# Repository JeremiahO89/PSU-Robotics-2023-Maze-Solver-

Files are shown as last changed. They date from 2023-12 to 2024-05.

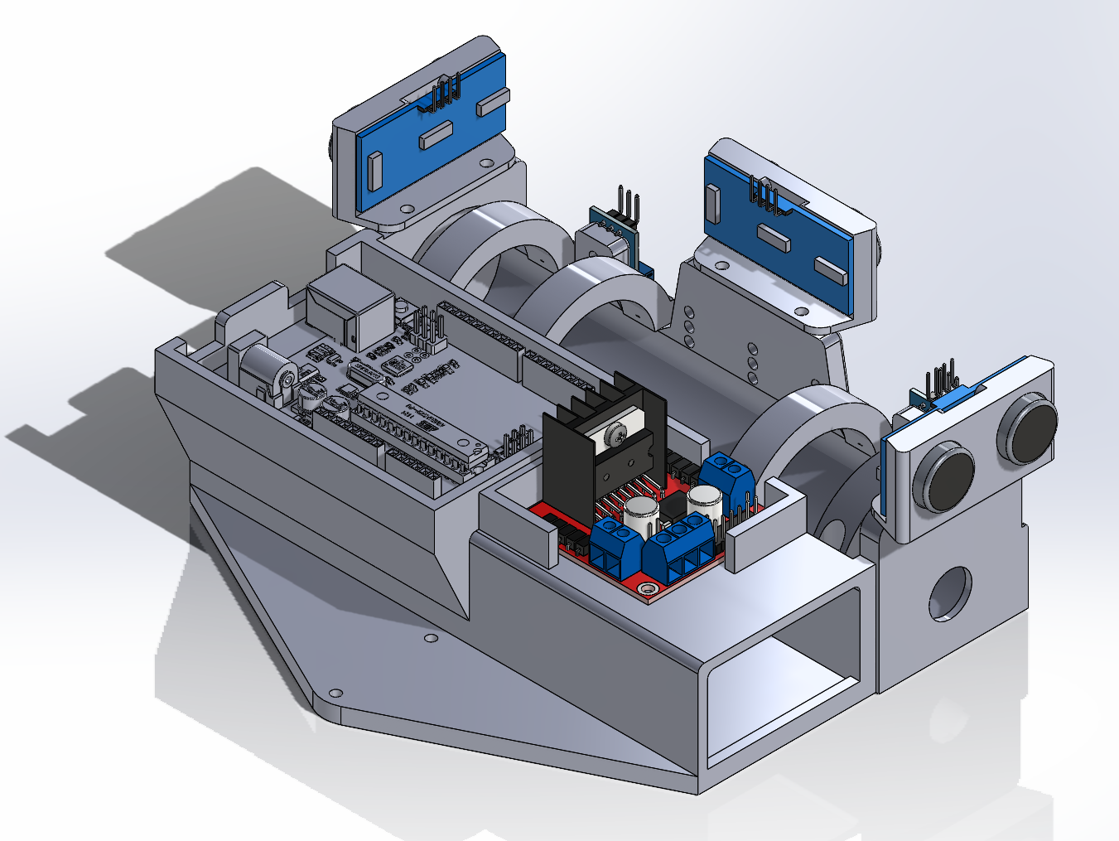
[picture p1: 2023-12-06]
Media/Screenshot 2023-12-06 145228.png

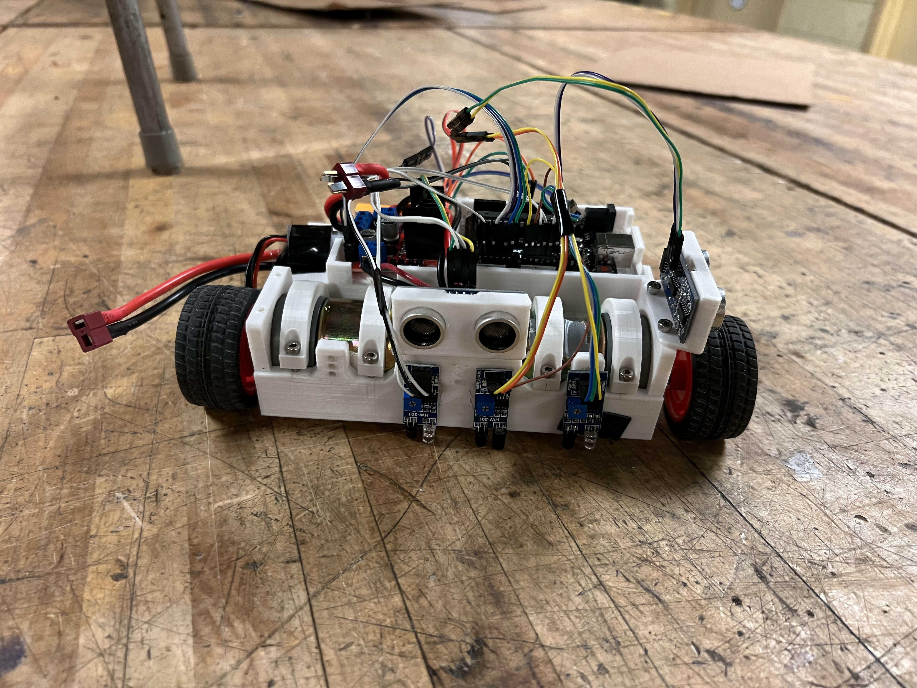
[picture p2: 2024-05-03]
Media/Finished bot.jpg

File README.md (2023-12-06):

# PSU-Robotics-2023-Maze-Solver-
This repository includes CAD and the necessary code to build a maze solving robot using basic Arduino hardware. It received 1st place at the Fall 2024 PSU Robotics Challenge 

This robot competed under the name "I Don't Care". It's design can be accredited to Jeremiah Ondrasik (jjo5541@psu.edu), Teagan Sharp (tjs6866@psu.edu), and Sydney Graver (sjg6347@psu.edu).

The CAD includes 7 SolidWorks part files and 1 assembly. To have the assembly file work correctly the files will need to properly selected when opening the file. For the final design the right Sonic sensor was not used as the Arduino didn't have enough digital pins. Also the motors, wheels and batteries weren't CADed due to time constraints. If there are any issues feel free to contact Jeremiah as he did the CAD design, Teagan helped with the robot design.

The code file nameed Challenge_Final was used on the final robot when it went to competition. The New Ping arduino library needs to be downloaded for the program to work properly. There are still a few issues with the line fowling as we ran into a major a constraint with the arduino's processing power. We originally had a very well defined line fowling code which only used the IR sensors however once we implemented the depth first searching algorithm (with the Ultrasonic sensors) we ran into processing issues of which we didn't have time to resolve (the old code is also included). This caused us to simplify the code a lot, which makes it very jerky, however it still completed the intended goal of solving the mazes within the time constant, and doing it faster than all of the other teams. If there are any questions with the code Jeremiah wrote the majority of it and Teagan / Sydney solved some of the remaining issues. 

If there are any questions about the composition Teagan should be contacted as he entered the robot into the composition.

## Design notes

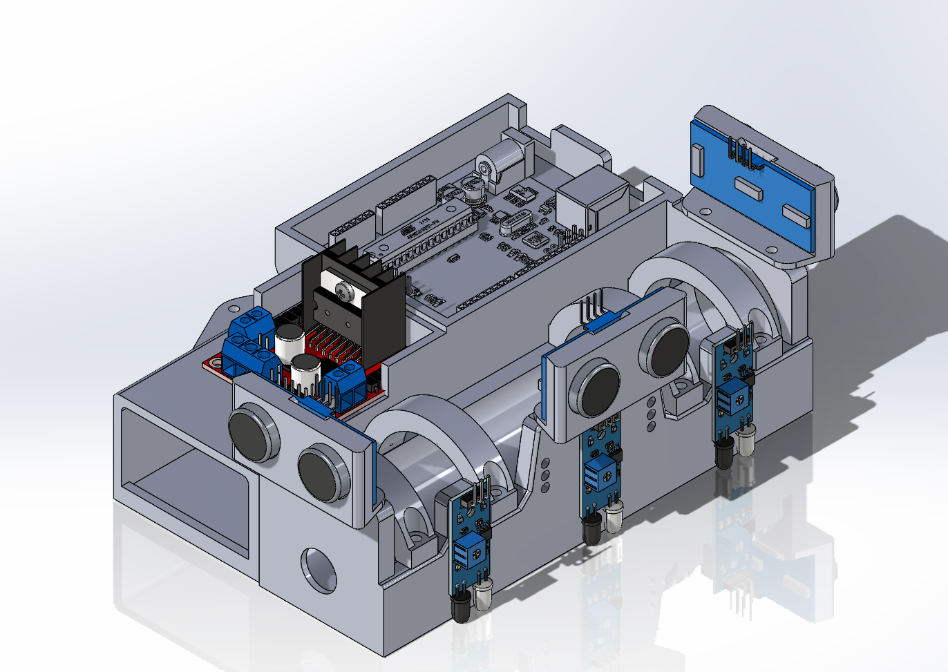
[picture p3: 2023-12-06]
Media/Screenshot 2023-12-06 145203.png

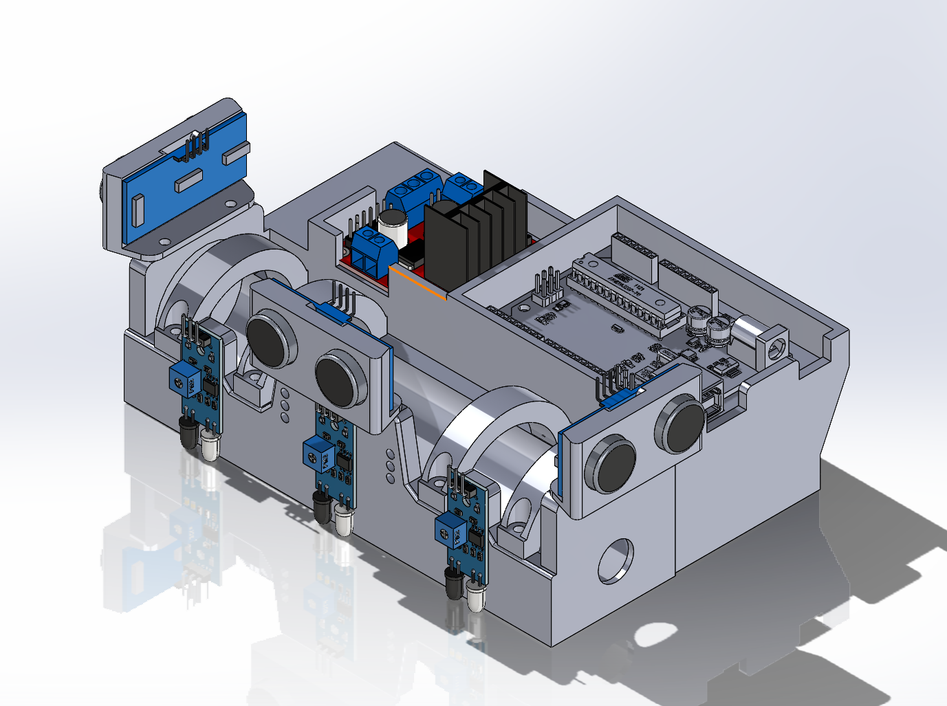
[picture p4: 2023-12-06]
Media/Screenshot 2023-12-06 145058.png

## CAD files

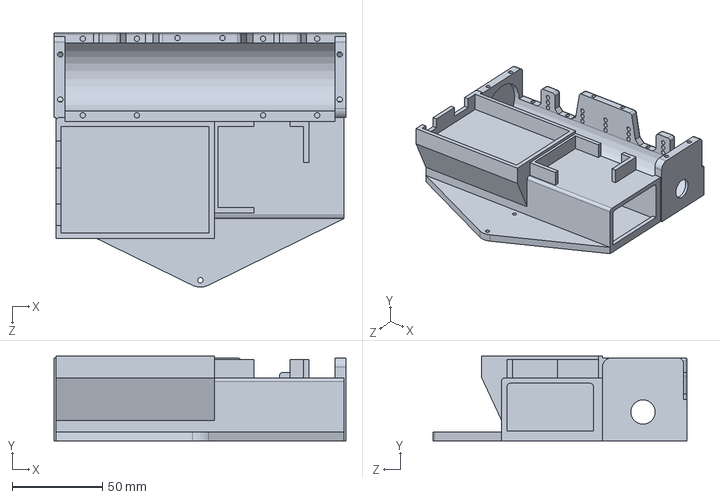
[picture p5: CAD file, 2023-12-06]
CAD/Main Chassis.SLDPRT
162.0 x 47.0 x 141.1 mm

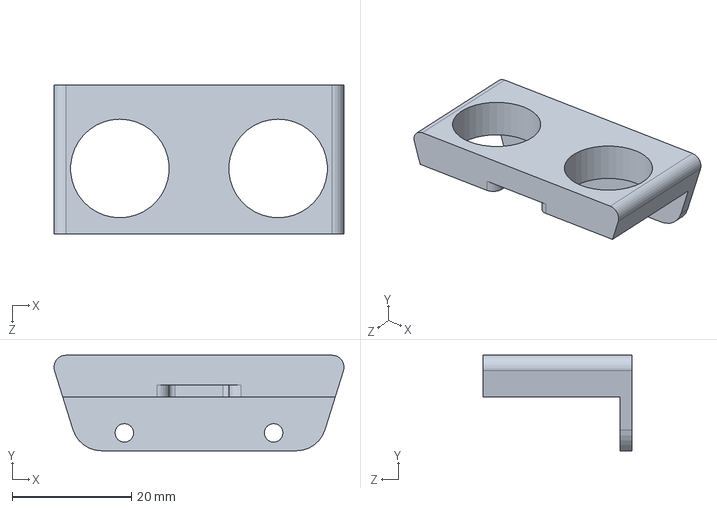
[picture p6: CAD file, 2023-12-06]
CAD/Sonic Sensor Mount.SLDPRT
48.5 x 16.0 x 25.0 mm

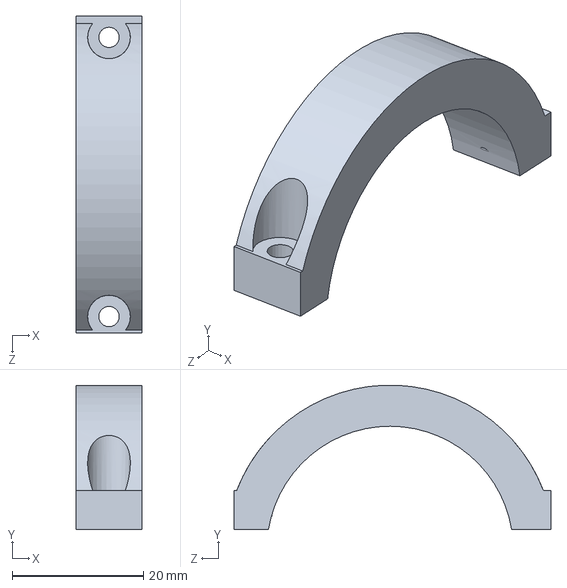
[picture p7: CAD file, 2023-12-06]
CAD/Motor clamp.SLDPRT
10.0 x 22.0 x 48.2 mm

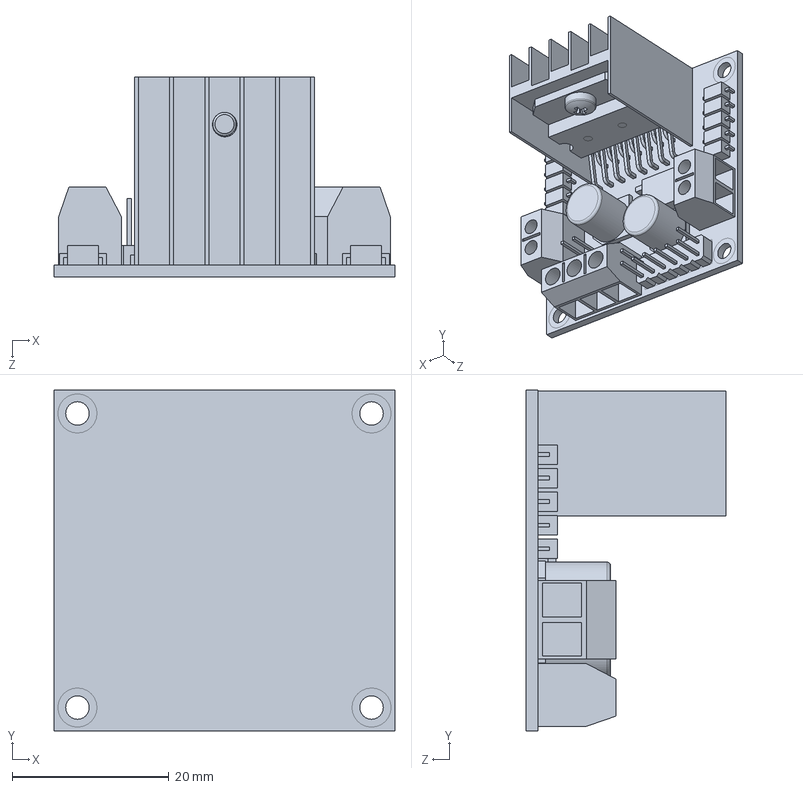
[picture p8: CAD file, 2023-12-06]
CAD/H_Bridg motor driver L298N.SLDPRT
43.5 x 43.5 x 25.5 mm

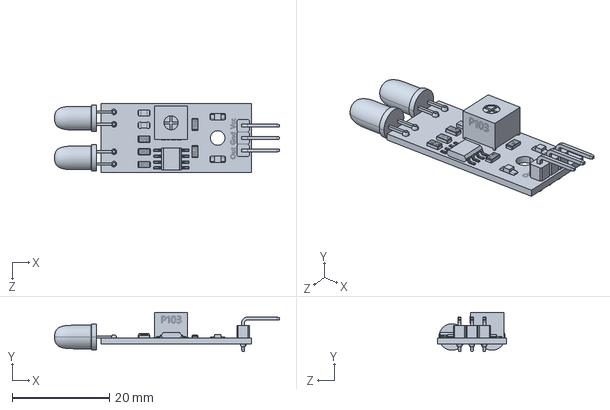
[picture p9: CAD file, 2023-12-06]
CAD/IRsensor.SLDPRT
46.3 x 8.05 x 14.2 mm

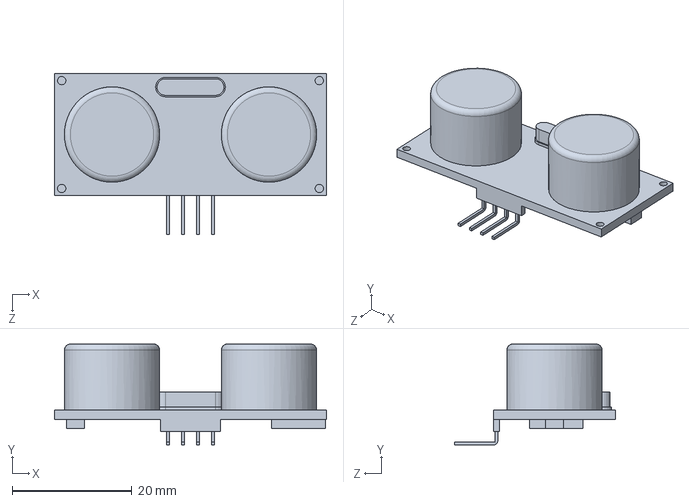
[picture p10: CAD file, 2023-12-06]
CAD/Ultrasonic Sensor.SLDPRT
45.4 x 16.9 x 26.9 mm

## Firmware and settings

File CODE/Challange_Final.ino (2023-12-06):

// This was the final code used in the composition

#include <NewPing.h>

// Pin Inputs
const int L_MOTOR_FORWARD = 3;
const int L_MOTOR_BACKWARD = 4;
const int R_MOTOR_FORWARD = 5;
const int R_MOTOR_BACKWARD = 6;
const int IR_Right = 2;
const int IR_Left = 9;
const int IR_Turn = 8;
const int Trig_Left = 13; 
const int Echo_Left = 12;
const int Trig_Middle = 11;
const int Echo_Middle = 10;

NewPing sonarLeft(Trig_Left, Echo_Left, 50);
NewPing sonarMiddle(Trig_Middle, Echo_Middle, 100);

// Constant variables
const int wall_dist = 20;
const int NINE_DEG = 125;
const int ONE_EIGHT_DEG = 300;

int status_Left = 0;
int status_Right = 0;
int status_Turn = 0;

int distance_Left = 0;
int distance_Middle = 0;
int right_check = 0;

// motor positions
void stopMoving(){
  digitalWrite(L_MOTOR_FORWARD, LOW);
  digitalWrite(L_MOTOR_BACKWARD, LOW);
  digitalWrite(R_MOTOR_FORWARD, LOW);
  digitalWrite(R_MOTOR_BACKWARD, LOW);
}
void moveForward(){
  digitalWrite(L_MOTOR_FORWARD, HIGH);
  digitalWrite(L_MOTOR_BACKWARD, LOW);
  digitalWrite(R_MOTOR_FORWARD, HIGH);
  digitalWrite(R_MOTOR_BACKWARD, LOW);
}
void moveBackward(){
  digitalWrite(L_MOTOR_FORWARD, LOW);
  digitalWrite(L_MOTOR_BACKWARD, HIGH);
  digitalWrite(R_MOTOR_FORWARD, LOW);
  digitalWrite(R_MOTOR_BACKWARD, HIGH);
}
void turnRight(){
  digitalWrite(L_MOTOR_FORWARD, LOW);
  digitalWrite(L_MOTOR_BACKWARD, HIGH);
  digitalWrite(R_MOTOR_FORWARD, HIGH);
  digitalWrite(R_MOTOR_BACKWARD, LOW);
}
void turnLeft(){
  digitalWrite(L_MOTOR_FORWARD, HIGH);
  digitalWrite(L_MOTOR_BACKWARD, LOW);
  digitalWrite(R_MOTOR_BACKWARD, LOW);
  digitalWrite(R_MOTOR_BACKWARD, HIGH);
}
void spinOut(){
  digitalWrite(L_MOTOR_FORWARD, HIGH);
  digitalWrite(L_MOTOR_BACKWARD, LOW);
  digitalWrite(R_MOTOR_BACKWARD, LOW);
  digitalWrite(R_MOTOR_BACKWARD, HIGH);
  delay(1000000000000);
}

void IR_get_data(){
  status_Left = digitalRead(IR_Left);
  status_Right = digitalRead(IR_Right);
  status_Turn = digitalRead(IR_Turn);
}

void setup() {
  //Serial.begin(9600);
  // Pin Setup
  pinMode (L_MOTOR_FORWARD, OUTPUT);
  pinMode (L_MOTOR_BACKWARD, OUTPUT);
  pinMode (R_MOTOR_FORWARD, OUTPUT);
  pinMode (R_MOTOR_BACKWARD, OUTPUT);
  pinMode (IR_Right, INPUT);
  pinMode (IR_Left, INPUT);
  pinMode (IR_Turn, INPUT);

// 5 second pause
  stopMoving();
  delay(5000);
 
  }


int timer = 0;

void loop() {

  IR_get_data();

  if (timer % 300 == 0){
  distance_Left = (sonarLeft.ping_cm());
  distance_Middle = (sonarMiddle.ping_cm());}
  //Serial.println(distance_Middle);
  
  // turn 180 no more path
  if (((distance_Middle <= 25) && (distance_Middle > 0)) && ((distance_Left < 15) && (distance_Left > 0))) {
    //spinOut();
    // turn the first 90
    turnLeft(); 
    delay(340);
    moveForward;
    delay(100);
    stopMoving();
    delay(500);
    right_check = (sonarLeft.ping_cm());
    if ((right_check >= 12 || right_check == 0)) {
      turnLeft(); 
      delay(200);
      stopMoving();
      delay(500);
    }
  }

  // Turn 90deg left   there is an open path
  else if (status_Turn == 1 && (distance_Left >= 15 || distance_Left == 0)) {
    //spinOut();
    // turn the first 90
    turnLeft(); 
    delay(100);
    stopMoving();
    delay(500);
  }

  // Drive on the Line
  // Center to the right 
  
    else if (status_Left == 0 && status_Right == 1 && status_Turn == 0) {
    turnRight();
    delay(2);
    stopMoving();
    delay(.25);
    }
// center to the left
  else if (status_Left == 1 && status_Right == 0 && status_Turn == 0) {
    turnLeft(); 
    delay(2);
    stopMoving();
    delay(.25);
    }
  
  // else drive forwards
  else if (((status_Left == 0 && status_Right == 0) || (status_Left == 1 && status_Right == 1)) && (distance_Middle >= 10 || distance_Middle < 4) && (status_Turn == 0 || distance_Left < 15)){
    
      moveForward(); 
      delay(5);
      stopMoving();
      delay(.25);

    if (status_Turn == 1 && distance_Left < 15){
      moveForward(); 
      delay(5);
      stopMoving();
      delay(.25);

    }
  }
  else {
    turnLeft(); 
    delay(40);
    stopMoving();
    delay(500);
  }
}

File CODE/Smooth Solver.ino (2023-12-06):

// This file is still a work in progress and was not used in the final design

#include <NewPing.h>

// Pin Inputs
const int L_MOTOR_FORWARD = 3;
const int L_MOTOR_BACKWARD = 4;
const int R_MOTOR_FORWARD = 5;
const int R_MOTOR_BACKWARD = 6;
const int IR_Right = 2;
const int IR_Left = 9;
const int IR_Turn = 8;
const int Trig_Left = 13; 
const int Echo_Left = 12;
const int Trig_Middle = 11;
const int Echo_Middle = 10;

NewPing sonarLeft(Trig_Left, Echo_Left, 100);
NewPing sonarMiddle(Trig_Middle, Echo_Middle, 100);

// Constant variables
const int wall_dist = 20;
const int NINE_DEG = 125;
const int ONE_EIGHT_DEG = 300;

int status_Left = 0;
int status_Right = 0;
int status_Turn = 0;

int distance_Left = 0;
int distance_Middle = 0;

// motor positions
void stopMoving(){
  digitalWrite(L_MOTOR_FORWARD, LOW);
  digitalWrite(L_MOTOR_BACKWARD, LOW);
  digitalWrite(R_MOTOR_FORWARD, LOW);
  digitalWrite(R_MOTOR_BACKWARD, LOW);
}
void moveForward(){
  digitalWrite(L_MOTOR_FORWARD, HIGH);
  digitalWrite(L_MOTOR_BACKWARD, LOW);
  digitalWrite(R_MOTOR_FORWARD, HIGH);
  digitalWrite(R_MOTOR_BACKWARD, LOW);
}
void moveBackward(){
  digitalWrite(L_MOTOR_FORWARD, LOW);
  digitalWrite(L_MOTOR_BACKWARD, HIGH);
  digitalWrite(R_MOTOR_FORWARD, LOW);
  digitalWrite(R_MOTOR_BACKWARD, HIGH);
}
void turnRight(){
  digitalWrite(L_MOTOR_FORWARD, LOW);
  digitalWrite(L_MOTOR_BACKWARD, HIGH);
  digitalWrite(R_MOTOR_FORWARD, HIGH);
  digitalWrite(R_MOTOR_BACKWARD, LOW);
}
void turnLeft(){
  digitalWrite(L_MOTOR_FORWARD, HIGH);
  digitalWrite(L_MOTOR_BACKWARD, LOW);
  digitalWrite(R_MOTOR_BACKWARD, LOW);
  digitalWrite(R_MOTOR_BACKWARD, HIGH);
}

void leftLoop(){
    while (status_Left == 1 && status_Right == 0){
        IR_get_data();
        turnRight(); 
        delay(.5);
        stopMoving();
        delay(.25);
        }
}

void rightLoop(){
    while (status_Left == 0 && status_Right == 1){
        IR_get_data();
        turnLeft(); 
        delay(.5);
        stopMoving();
        delay(.25);
        }
}

void IR_get_data(){
  status_Left = digitalRead(IR_Left);
  status_Right = digitalRead(IR_Right);
  status_Turn = digitalRead(IR_Turn);
}

void setup() {
  Serial.begin(19200);

  // Pin Setup
  pinMode (L_MOTOR_FORWARD, OUTPUT);
  pinMode (L_MOTOR_BACKWARD, OUTPUT);
  pinMode (R_MOTOR_FORWARD, OUTPUT);
  pinMode (R_MOTOR_BACKWARD, OUTPUT);
  pinMode (IR_Right, INPUT);
  pinMode (IR_Left, INPUT);
  pinMode (IR_Turn, INPUT);

// lights
  pinMode (7, OUTPUT);
  pinMode (1, OUTPUT);
  digitalWrite(7, LOW);  
  digitalWrite(1, LOW);  

// 5 second pause
  stopMoving();
  delay(5000);

// lights
  digitalWrite(7, HIGH); 
  digitalWrite(1, HIGH); 
  }

void loop() {
  IR_get_data();
  distance_Left = (sonarLeft.ping_cm());
  distance_Middle = (sonarMiddle.ping_cm());

  //Serial.println("Left: " + String(distance_Left) + "   Middle: " + String(distance_Middle));
  //Serial.println("IR_L: " + String(status_Left) + "   IR_R:" + String(status_Right));
  
  // turn 180 no more path
  if (((distance_Middle < 10) && (distance_Middle > 2)) && ((distance_Left < 10) && (distance_Left > 2))) {
    
    // turn the first 90
    while (status_Left == 0){
        IR_get_data();
        turnLeft(); 
        delay(.5);
        stopMoving();
        delay(.25);}
    delay(250);
    //turn the over the line
    while (status_Left == 1){
        IR_get_data();
        turnLeft(); 
        delay(.5);
        stopMoving();
        delay(.25);}
    delay(250);
    //turn the second 90 
    while (status_Left == 0){
        IR_get_data();
        turnLeft(); 
        delay(.5);
        stopMoving();
        delay(.25);}
    delay(250);
    // center on the line
    while (status_Right == 0){
        IR_get_data();
        turnLeft(); 
        delay(.5);
        stopMoving();
        delay(.25);}
  }

  // Turn 90deg left   there is an open path
  else if (status_Turn == 1 && distance_Left > 25) {
    // turn the first 90
    while (status_Left == 0){
        IR_get_data();
        turnLeft(); 
        delay(.5);
        stopMoving();
        delay(.25);}
    
    delay(250);
    // center on the line
    while (status_Right == 0){
        IR_get_data();
        turnLeft(); 
        delay(.5);
        stopMoving();
        delay(.25);}
  }

  // Drive on the Line
  else if (status_Left == 0 && status_Right == 1) {
    while (status_Left == 0 && status_Right == 1) {
    IR_get_data();
    turnRight();
    delay(.5);
    stopMoving();
    delay(.25);
    }
  }
  else if (status_Left == 1 && status_Right == 0) {
    while (status_Left == 1 && status_Right == 0){
    IR_get_data();
    turnLeft(); 
    delay(.5);
    stopMoving();
    delay(.25);
    }
  }
  
  // else drive forwards
  else {
    int timer = 0;

    while (((status_Left == 0 && status_Right == 0) || (status_Left == 1 && status_Right == 1)) && status_Turn == 0 && distance_Middle > 5){
    
      // adds a delay between sonic pings
      if ((timer % 200) == 0){
        distance_Left = (sonarLeft.ping_cm());
        distance_Middle = (sonarLeft.ping_cm());}

      IR_get_data();
      moveForward(); 
      delay(.5);
      stopMoving();
      delay(.25);
      timer += 1;
    }
  }
}
